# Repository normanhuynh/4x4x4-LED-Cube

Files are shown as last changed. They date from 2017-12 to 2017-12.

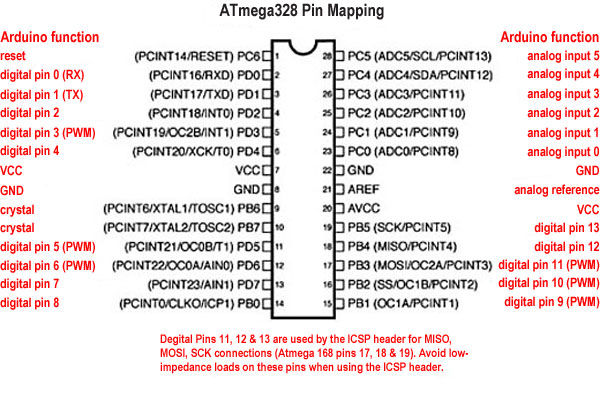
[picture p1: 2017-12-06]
Datasheets/ATmega328 Pin Mapping.jpg

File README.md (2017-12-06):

# 4x4x4 LED Cube

This is a hand-soldered, reprogrammable 4x4x4 LED cube that uses Arduino - an open source IDE used to control user-made projects. This compact cube lights up with different patterns and is used to impress friends and family or as an amazing decoration for your desk. Of course, the hardware is not supplied in this repo - you will have to source that yourself.

# Main Components

  - ATmega328 microcontroller 
  - 2 x 74HC595N shift registers 
  - 4x4x4 cube matrix
  - 4 x BC327 transistors that control each layer of the cube.

Datasheets for the ATmega328 and for the 74HC595N are enclosed in the enclosed .zip file.

# How it Works - Quick Rundown
The LEDs are controlled by 2 shift registers that receive 16 bits from the programmed microcontroller. The shift registers then send out ON/OFF states to each layer of the cube’s cathodes before each corresponding layer anode is written to a LOW state in order to light the LEDs that were written to a LOW state. This process is rapidly repeated to give the impression that all LEDs in each layer are lit up simultaneously.

# Applications Used

  - **Arduino** - to create the LED cube sketch code
  - **Eagle** - to create the PCB and schematic

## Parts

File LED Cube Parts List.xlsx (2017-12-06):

Device | Value | Package | Digikey Part # | Amount/cube | Unit Cost | Total Cost
Capacitor | 4.7uF | E2-5 | 493-6100-1-ND (http://www.digikey.ca/product-detail/en/UVR1H4R7MDD1TA/493-6100-1-ND/3438489) | 1.00 | $0.33 | $0.33
Capacitor | 100uF | O805 | 490-10510-1-ND (http://www.digikey.ca/product-detail/en/GRM21BR60G107ME15L/490-10510-1-ND/5026439) | 1.00 | $1.61 | $1.61
Capacitor | 100nF | O805 | 1276-1007-1-ND (http://www.digikey.ca/product-detail/en/CL21F104ZBCNNNC/1276-1007-1-ND/3889093) | 4.00 | $0.04 | $0.16
Capacitor | 47uF | O805 | 1276-2420-1-ND (http://www.digikey.ca/product-detail/en/CL21A476MQCLRNC/1276-2420-1-ND/3890506) | 1.00 | $0.97 | $0.97
Capacitor | 1nF | O805 | 399-1147-1-ND (http://www.digikey.ca/product-detail/en/C0805C102K5RACTU/399-1147-1-ND/411422) | 1.00 | $0.13 | $0.13
9V-5V converter | n/a | TO220 | MC7805CT-BPMS-ND (http://www.digikey.ca/product-detail/en/MC7805CT-BP/MC7805CT-BPMS-ND/804682) | 1.00 | $0.62 | $0.62
USB header | n/a | FCI 10103594-0001LF | 609-4050-1-ND (http://www.digikey.ca/product-detail/en/10103594-0001LF/609-4050-1-ND/2350357) | 1.00 | $0.93 | $0.93
Resistor | 220 Ohms | O805 | RHM220CHCT-ND (http://www.digikey.ca/product-detail/en/MCR10ERTF2200/RHM220CHCT-ND/2796523) | 16.00 | $0.03 | $0.42
Push button | n/a | Tactile PTH | 450-1650-ND (http://www.digikey.ca/product-detail/en/1825910-6/450-1650-ND/1632536) | 1.00 | $0.13 | $0.13
EBC BC327 PNP | n/a | TO92 | BC327BU-ND (http://www.digikey.ca/product-detail/en/BC327BU/BC327BU-ND/975522) | 4.00 | $0.28 | $1.12
ATMega328P | n/a | DIL28-3 | ATMEGA328P-PU-ND (http://www.digikey.ca/product-detail/en/ATMEGA328P-PU/ATMEGA328P-PU-ND/1914589) | 1.00 | $4.70 | $4.70
Battery | 9V | n/a | n/a | 1.00 | $0.00 | $0.00
Battery Socket | n/a | n/a | n/a | 1.00 | $0.00 | $0.00
Capacitor | 22pF | O805 | 399-1113-1-ND (http://www.digikey.ca/product-detail/en/C0805C220J5GACTU/399-1113-1-ND/411388) | 2.00 | $0.13 | $0.26
Crystal | 16MHz | HC49/S | 887-1591-ND (http://www.digikey.ca/product-detail/en/AS-16.000MAHK-B/887-1591-ND/3182299) | 1.00 | $0.78 | $0.78
Pin Header | n/a | 1x1 | n/a | 4.00 | $0.00 | $0.00
Pin Header | n/a | 1x13 | n/a | 4.00 | $0.00 | $0.00
74HC595N | n/a | SOIC-16 0.154"x.390mm | MM74HC595MXCT-ND (http://www.digikey.ca/product-detail/en/MM74HC595MX/MM74HC595MXCT-ND/1626252) | 2.00 | $0.60 | $0.60
 |  |  |  |  |  | $12.75

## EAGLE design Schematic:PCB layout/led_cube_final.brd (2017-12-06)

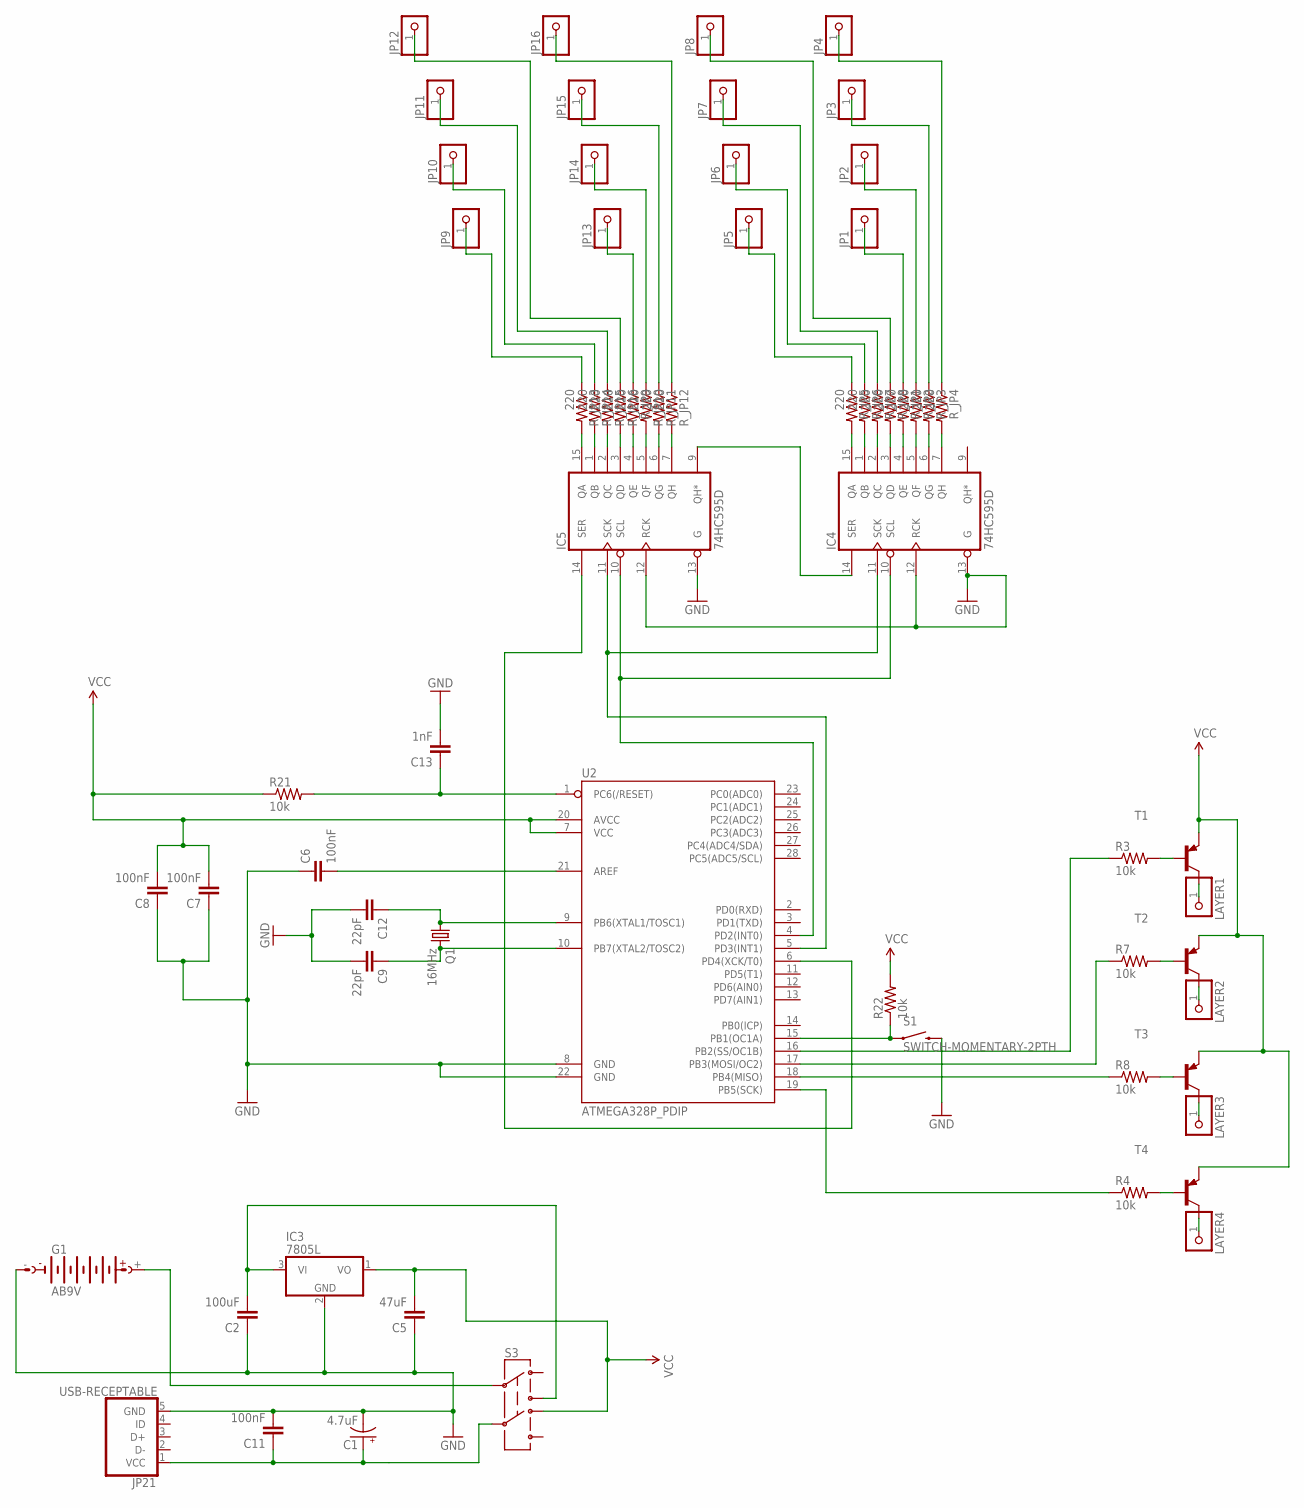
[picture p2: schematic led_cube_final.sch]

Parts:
C1: 4.7uF; E2-5
C2: 100uF; 0805
C5: 47uF; 0805
C6, C7, C8, C11: 100nF; 0805
C9, C12: 22pF; 0805
C13: 1nF; 0805
G1: AB9V
IC3: 7805L; TO92
IC4, IC5: 74HC595D; SO16
JP1, JP2, JP3, JP4, JP5, JP6, JP7, JP8, JP9, JP10, JP11, JP12, JP13, JP14, JP15, JP16: PINHD-1X1; 1X01
JP21: USB-RECEPTABLE; FCI-10103594-0001LF
LAYER1, LAYER2, LAYER3, LAYER4: PINHD-1X1; 1X01
Q1: 16MHz; HC49/S
R3, R4, R7, R8, R21, R22: 10k; 0805
R_JP1, R_JP2, R_JP3, R_JP4, R_JP5, R_JP6, R_JP7, R_JP8, R_JP9, R_JP10, R_JP11, R_JP12, R_JP13, R_JP14, R_JP15, R_JP16: 220; 0805
S1: SWITCH-MOMENTARY-2PTH; TACTILE-PTH
S3: SWITCH-DPDTOS; OS
T1, T2, T3, T4: BC327-16-PNP-TO92-EBC; TO92-EBC
U2: ATMEGA328P_PDIP; DIL28-3

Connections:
GND: C1.-, C2.1, C5.1, C6.1, C7.1, C8.1, C9.2, C11.2, C12.2, C13.2, G1.-, IC3.2 (GND), IC4.8 (GND), IC4.12 (RCK), IC4.13 (G), IC5.8 (GND), IC5.12 (RCK), IC5.13 (G), JP21.5 (GND), S1.3 (2), U2.8 (GND), U2.22 (GND)
unnamed: R4.2, T4.B
unnamed: R3.2, T1.B
unnamed: R7.2, T2.B
unnamed: IC4.10 (SCL), IC5.10 (SCL), U2.4 (PD2(INT0))
unnamed: JP1.1, R_JP1.1
unnamed: JP2.1, R_JP2.1
unnamed: R8.2, T3.B
unnamed: JP3.1, R_JP3.1
unnamed: JP4.1, R_JP4.1
unnamed: JP5.1, R_JP5.1
unnamed: JP6.1, R_JP6.1
unnamed: R22.1, S1.1, U2.15 (PB1(OC1A))
unnamed: LAYER3.1, T3.C
unnamed: R4.1, U2.19 (PB5(SCK))
unnamed: JP7.1, R_JP7.1
unnamed: JP8.1, R_JP8.1
unnamed: JP13.1, R_JP9.1
unnamed: JP14.1, R_JP10.1
unnamed: JP15.1, R_JP11.1
unnamed: JP16.1, R_JP12.1
unnamed: JP9.1, R_JP13.1
unnamed: JP10.1, R_JP14.1
unnamed: JP11.1, R_JP15.1
unnamed: JP12.1, R_JP16.1
unnamed: IC4.7 (QH), R_JP4.2
unnamed: IC4.6 (QG), R_JP3.2
unnamed: IC4.5 (QF), R_JP2.2
unnamed: IC4.4 (QE), R_JP1.2
unnamed: IC4.3 (QD), R_JP8.2
unnamed: IC4.2 (QC), R_JP7.2
unnamed: IC4.1 (QB), R_JP6.2
unnamed: IC4.15 (QA), R_JP5.2
unnamed: IC5.7 (QH), R_JP12.2
unnamed: IC5.6 (QG), R_JP11.2
unnamed: IC5.5 (QF), R_JP10.2
unnamed: IC5.4 (QE), R_JP9.2
unnamed: IC5.3 (QD), R_JP16.2
unnamed: IC5.2 (QC), R_JP15.2
unnamed: IC5.1 (QB), R_JP14.2
unnamed: IC5.15 (QA), R_JP13.2
unnamed: IC4.14 (SER), IC5.9 (QH*)
unnamed: LAYER4.1, T4.C
unnamed: R8.1, U2.18 (PB4(MISO))
unnamed: IC4.11 (SCK), IC5.11 (SCK), U2.5 (PD3(INT1))
unnamed: C2.2, IC3.3 (VI), S3.3
unnamed: C9.1, Q1.2, U2.10 (PB7(XTAL2/TOSC2))
unnamed: IC5.14 (SER), U2.6 (PD4(XCK/T0))
unnamed: R7.1, U2.17 (PB3(MOSI/OC2))
unnamed: C12.1, Q1.1, U2.9 (PB6(XTAL1/TOSC1))
unnamed: LAYER2.1, T2.C
unnamed: LAYER1.1, T1.C
unnamed: R3.1, U2.16 (PB2(SS/OC1B))
unnamed: C13.1, R21.2, U2.1 (PC6(/RESET))
unnamed: C6.2, U2.21 (AREF)
unnamed: G1.+, S3.2
unnamed: C1.+, C11.1, JP21.1 (VCC), S3.5
VCC: C5.2, C7.2, C8.2, IC3.1 (VO), IC4.16 (VCC), IC5.16 (VCC), R21.1, R22.2, S3.4, T1.E, T2.E, T3.E, T4.E, U2.7 (VCC), U2.20 (AVCC)

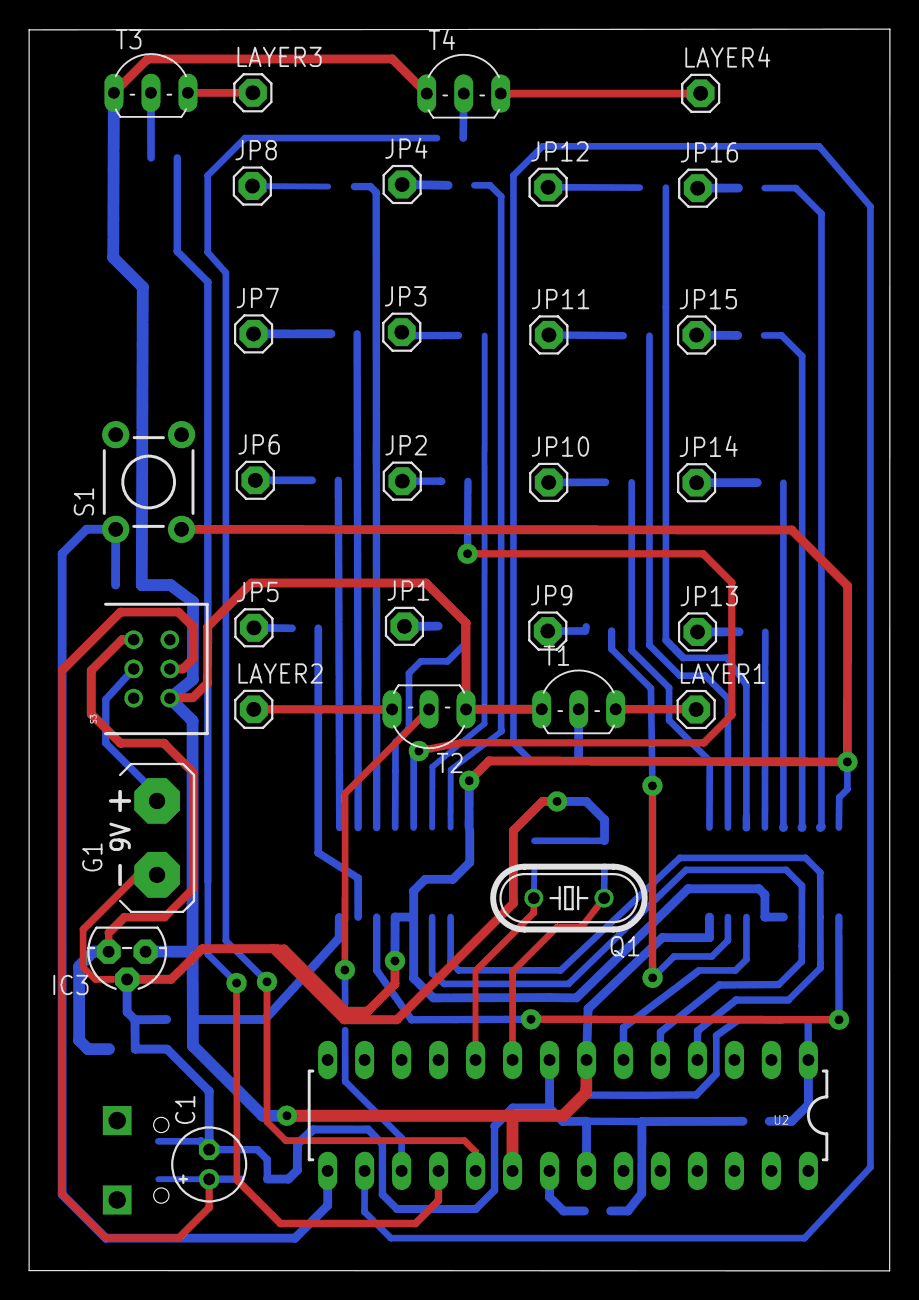
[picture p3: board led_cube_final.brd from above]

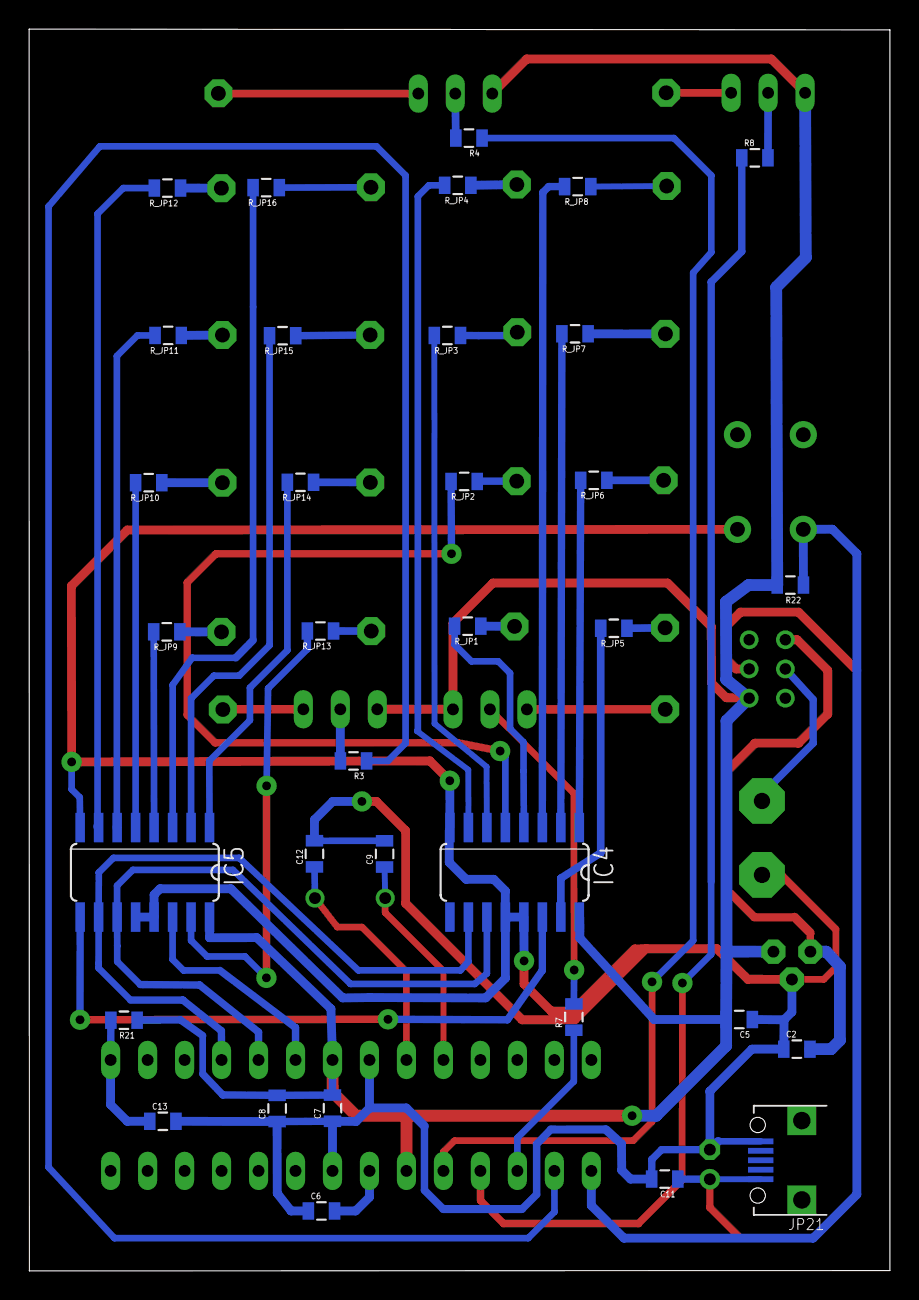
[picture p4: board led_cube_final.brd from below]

Board: 2 copper layers, 59.1 x 85.3 mm, 65 parts (34 on the bottom side), 58 nets.

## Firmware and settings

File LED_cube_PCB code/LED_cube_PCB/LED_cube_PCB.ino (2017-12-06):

/*
Code written by Norman Huynh
Date Written: January 25, 2015
File name: LED_cube_PCB.ino
An all-in-one file that controls the prototype LED cube created on the breadboard */

/*---------------------------------------
Variable Declaration
---------------------------------------*/
// Cube anode pin mapping
int layer[4] = {10, 11, 12, 13}; //10 11 12 13 ] 8, 9, 10, 11

// 595 pin mapping
int dataPin = 4; // 4 5
int clockPin = 3; // 3 6
int latchPin = 2;  // 2 7                  
                    
// Animation constants
int layerAllOn = 0b00000000;                                 // Use twice in shiftOut16 to make all 16 LEDS in a layer on
int layerAllOff = 0b11111111;                                // same as above, but makes all 16 LEDs off instead

int allOnStates[] = {LOW, layerAllOn};                       // Lists used as input for 1 parameter for entire cube layer control for 1 ON/OFF state
int allOffStates[] = {HIGH, layerAllOff};


//-----------------------------//
// Animation Frames
//-----------------------------//
// bounce frames
int bounceAnodes[13][4] = { {LOW, HIGH, HIGH, HIGH}, {LOW, LOW, HIGH, HIGH}, {LOW, LOW, LOW, HIGH}, {LOW, LOW, LOW, LOW},
                            {HIGH, LOW, LOW, LOW}, {HIGH, HIGH, LOW, LOW}, {HIGH, HIGH, HIGH, LOW},{HIGH, HIGH, HIGH, LOW},
                            {HIGH, HIGH, LOW, LOW}, {HIGH, LOW, LOW, LOW}, {LOW, LOW, LOW, LOW}, {LOW, LOW, LOW, HIGH}, 
                            {LOW, LOW, HIGH, HIGH} };
int bounceCathodes[13][4][2] = { 
                              { {layerAllOn, layerAllOn}, {layerAllOn, layerAllOn}, {layerAllOn, layerAllOn}, {layerAllOn, layerAllOn} }, // [frame][layer][LEDs]
                              { {layerAllOn, layerAllOn}, {layerAllOn, layerAllOn}, {layerAllOn, layerAllOn}, {layerAllOn, layerAllOn} },
                              { {layerAllOn, layerAllOn}, {layerAllOn, layerAllOn}, {layerAllOn, layerAllOn}, {layerAllOn, layerAllOn} },
                              { {layerAllOn, layerAllOn}, {layerAllOn, layerAllOn}, {layerAllOn, layerAllOn}, {layerAllOn, layerAllOn} },
                              { {layerAllOn, layerAllOn}, {layerAllOn, layerAllOn}, {layerAllOn, layerAllOn}, {layerAllOn, layerAllOn} },
                              { {layerAllOn, layerAllOn}, {layerAllOn, layerAllOn}, {layerAllOn, layerAllOn}, {layerAllOn, layerAllOn} },
                              { {layerAllOn, layerAllOn}, {layerAllOn, layerAllOn}, {layerAllOn, layerAllOn}, {layerAllOn, layerAllOn} },
                              { {layerAllOn, layerAllOn}, {layerAllOn, layerAllOn}, {layerAllOn, layerAllOn}, {layerAllOn, layerAllOn} },
                              { {layerAllOn, layerAllOn}, {layerAllOn, layerAllOn}, {layerAllOn, layerAllOn}, {layerAllOn, layerAllOn} },
                              { {layerAllOn, layerAllOn}, {layerAllOn, layerAllOn}, {layerAllOn, layerAllOn}, {layerAllOn, layerAllOn} },
                              { {layerAllOn, layerAllOn}, {layerAllOn, layerAllOn}, {layerAllOn, layerAllOn}, {layerAllOn, layerAllOn} },
                              { {layerAllOn, layerAllOn}, {layerAllOn, layerAllOn}, {layerAllOn, layerAllOn}, {layerAllOn, layerAllOn} },
                              { {layerAllOn, layerAllOn}, {layerAllOn, layerAllOn}, {layerAllOn, layerAllOn}, {layerAllOn, layerAllOn} }
                              };
                              
// explode frames
int explosionAnodes[7][4] = { {HIGH, HIGH, HIGH, LOW}, {HIGH, HIGH, LOW, LOW}, {HIGH, LOW, LOW, LOW}, {LOW, LOW, LOW, LOW}, {HIGH, LOW, LOW, LOW}, 
                             {HIGH, HIGH, LOW, LOW}, {HIGH, HIGH, HIGH, LOW} };
     
int explosionCathodes[7][4][2] = { 
                                { {0b11111001, 0b10011111}, {0b11111111, 0b11111111}, {0b11111111, 0b11111111}, {0b11111111, 0b11111111} },
                                { {0b11111001, 0b10011111}, {0b11111001, 0b10011111}, {0b11111111, 0b11111111}, {0b11111111, 0b11111111} },
                                { {0b11111001, 0b10011111}, {0b11111001, 0b10011111}, {0b11111001, 0b10011111}, {0b11111111, 0b11111111} },
                                { {0b11111001, 0b10011111}, {0b11111001, 0b10011111}, {0b11111001, 0b10011111}, {0b00000110, 0b01100000} },
                                { {0b11111111, 0b11111111}, {0b10011111, 0b10011111}, {0b00000110, 0b01100000}, {0b00000110, 0b01100000} },
                                { {0b11111111, 0b11111111}, {0b11111111, 0b11111111}, {0b00000110, 0b01100000}, {0b00000110, 0b01100000} },
                                { {0b11111111, 0b11111111}, {0b11111111, 0b11111111}, {0b11111111, 0b11111111}, {0b00000110, 0b01100000} },
                                };
                                                               
//----------------------------------------------------//
// SETUP FUNCTION
//----------------------------------------------------//
void setup() {
  for (int anode = 0; anode <= 3; anode++) {
    pinMode(layer[anode], OUTPUT);
  }
  pinMode(dataPin, OUTPUT);
  pinMode(clockPin, OUTPUT);
  pinMode(latchPin, OUTPUT);  
}

//----------------------------------------------------//
// Utilities - Functions that do useful stuff
//----------------------------------------------------//
void shiftOut16(int byte1, int byte2) {
  /* Calls x2 shiftOut functions to output 16 bits from a list with 2 elements,
  each representing a byte */
  digitalWrite(latchPin, LOW);
  
  shiftOut(dataPin, clockPin, MSBFIRST, byte1);
  shiftOut(dataPin, clockPin, MSBFIRST, byte2);
  
  digitalWrite(latchPin, HIGH);
}  

void allState(int layerState[]) {
  /* accepts list with 3 parameters, with state of anode, and 2 bytes of all ON or OFF state */
  for (int anode = 0; anode <= 3; anode++) {
    digitalWrite(layer[anode], layerState[0]);
    shiftOut16(layerState[1], layerState[1]);
  }
}
  
void layerWrite(int timeDelay, int anodesList[][4], int cathodesList[][4][2], int amtFrames) {  
  /* takes a frame delay rate, list of anode states, list of cathode states, and number of frames to repeat */  
  allState(allOffStates);
  for (int frame = 0; frame < amtFrames; frame++) {
      for (int anode = 0; anode <= 3; anode++) {
        for (int flat = 0; flat <= 3; flat++) {
          digitalWrite(layer[anode], HIGH);        
          shiftOut16(cathodesList[frame][flat][0], cathodesList[frame][flat][1]);        
          digitalWrite(layer[anode], anodesList[frame][anode]);
          delay(timeDelay);
       }
     }
  }
}
//----------------------------------------------------//
// Working Cube Animations - functions that make the cube sexy
//----------------------------------------------------//                            
void upDown(int timeDelay, int anodesList[][4], int cathodesList[][4][2], int amtFrames) {
  layerWrite(timeDelay, anodesList, cathodesList, amtFrames);
}

void explosion(int timeDelay, int anodesList[][4], int cathodesList[][4][2], int amtFrames) {
  layerWrite(timeDelay, anodesList, cathodesList, amtFrames);
}

//----------------------------------------------------//
// MAIN LOOP
//----------------------------------------------------//
void loop() {
  explosion(5, explosionAnodes, explosionCathodes, 7);
  delay(3);
  upDown(5, bounceAnodes, bounceCathodes, 13);

}
  

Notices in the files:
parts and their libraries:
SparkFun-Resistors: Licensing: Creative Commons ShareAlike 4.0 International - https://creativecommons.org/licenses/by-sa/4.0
